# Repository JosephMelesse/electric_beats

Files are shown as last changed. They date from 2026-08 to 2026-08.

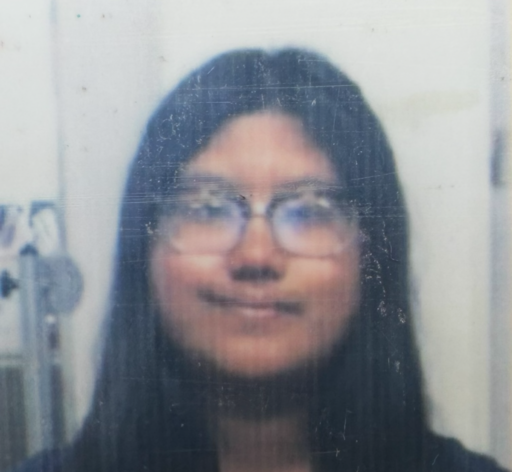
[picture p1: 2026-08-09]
web/client/src/assets/team_pics/ana_web.png

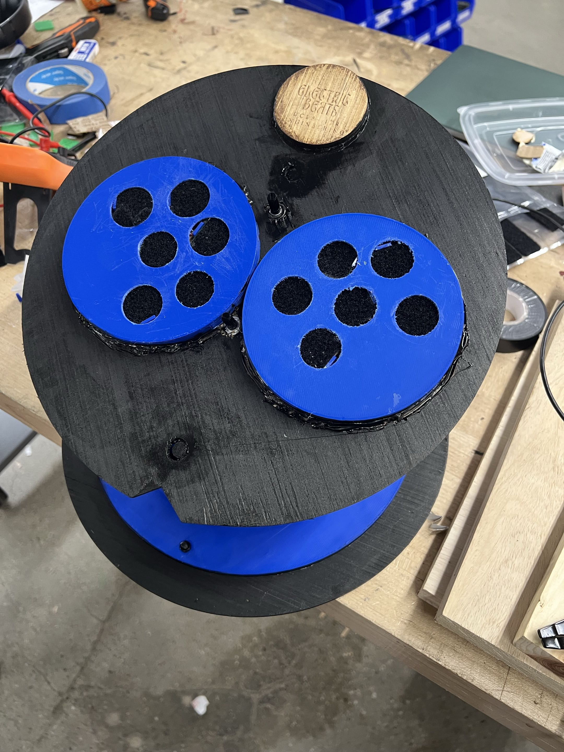
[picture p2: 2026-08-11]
web/client/src/assets/image.jpg

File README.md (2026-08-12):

# electric_beats

UCLA Engineering TR-1 Hack Project. A Pico 2 keypad wired to a browser. This
repo consists of the firmware, the web client and local server code, and any
miscellaneous files that are involved with the project.

It is a rhythm space shooter. A song stored in JSON schedules asteroids onto
twelve slots under a spaceship; press the matching key in time and the ship
turns and shoots. The Pico synthesizes the note it plays, so all audio comes
from the speaker on the board and the browser stays silent.

## Quick start

Copy the firmware to the board, then run the server:

```
cp firmware/code.py /media/$USER/CIRCUITPY/
cd web
npm install
npm start
```

Open http://localhost:5173 and press a key. Three songs ship in
`web/client/src/assets/song.json`; pick one from the menu above the canvas.

The board needs CircuitPython 10.x flashed once first, see `firmware/README.md`.

No board handy? The server still starts and serves the page, the game just
gets no input. There is no keyboard fallback.

Running the demo across two machines, one with the Pico and one on the
projector, is written up in `web/instruction.md`.

## Layout

| Path | What it is |
| --- | --- |
| `firmware/` | CircuitPython `code.py`, plus wiring and synth notes |
| `web/server/` | Serial bridge, websocket relay, static host |
| `web/client/` | React game canvas, bundled with esbuild |
| `misc/` | Sound sheets, pinout image, playing reference |

`DESIGN.md` covers the module split and what was cut.

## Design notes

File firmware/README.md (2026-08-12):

# Firmware

Reads twelve individual buttons, sends `K <key>` lines over USB serial at
115200, and synthesizes all game audio on the Pico. The browser is silent.

## Wiring

Each button connects its GPIO to GND; the firmware uses internal pull-ups.

| Signal | Pico 2 | Physical pin |
| --- | --- | --- |
| Buttons 1-6 | GP2, GP3, GP4, GP5, GP6, GP7 | 4, 5, 6, 7, 9, 10 |
| Button * | GP8 | 11 |
| Button 0 | GP9 | 12 |
| Button 9 | GP10 | 14 |
| Button 8 | GP11 | 15 |
| Button 7 | GP12 | 16 |
| Button # | GP13 | 17 |
| Amp I2S DIN | GP15 | 20 |
| Amp I2S BCLK | GP19 | 25 |
| Amp I2S LRC | GP20 | 26 |
| Amp VIN | VBUS 5V | 40 |
| Volume pot wiper | GP26 / ADC0 | 31 |
| Effect pot wiper | GP27 / ADC1 | 32 |
| Pot outer legs | 3V3 out and GND | 36, 38 |

The speaker (4 ohm, 3 W) connects directly to the amp's output terminals.
Do not put a resistor in the amp's power feed; if hardware attenuation is
ever needed again, it goes in series with a speaker wire.

## Sound

Each key plays one semitone of a chromatic scale from C4: `1` = C4 up to
`#` = B4, with `0` = A4 and `*` = A#4.

The volume pot (ADC0) sets the master level with a squared taper; full
clockwise is the MAX_VOLUME constant in `code.py`. Its outer legs are
wired so the ADC reads high at the quiet end, so `read_volume()` inverts
the reading; swap the pot's outer legs and that inversion comes out. The effect pot (ADC1)
selects the preset in three zones, left to right. A preset change only
affects new key presses. Zone edges have a dead band so a knob resting
on a boundary does not flicker.

Both knobs report over serial for the web client: `P <name>` for the
preset and `V <percent>` for the volume knob's position, each on change
and again every two seconds so a server that starts later catches up.
The percent is where the knob sits, not the level it produces, since
the taper is squared.

Each preset is a different waveform with a different effect on top, and
none is tied to a particular song:

| | bell (left) | reed (middle) | organ (right) |
| --- | --- | --- | --- |
| Waveform | chime | soft saw | drawbar organ |
| Effect | detune shimmer | 5.5 Hz vibrato | 4 Hz tremolo |
| Filter | low-pass 5 kHz | low-pass 3 kHz | low-pass 4 kHz |
| Release | 0.18 s | 0.15 s | 0.12 s |

Releases stay under 0.2 s so fast passages stay articulate. The tightest
spacing in the charts is a sixteenth at 70 bpm, about 214 ms, and a
longer tail would smear one note into the next.

All waveforms are built additively from sine harmonics that stay below
Nyquist, so naive saw/square aliasing cannot occur; filters are gentle
(Q 0.707) and note amplitudes are budgeted so summed voices cannot clip
inside the synth.

## Deploy

CircuitPython 10.x for the Pico 2 (flash the .uf2 from circuitpython.org
once), then copy `code.py` to the CIRCUITPY drive. It auto-reloads on
every copy; no build step. Everything used is built into CircuitPython,
no libraries to install.

Note: with CircuitPython the serial port carries the Python console, so
the server may see REPL noise besides the `K`, `P` and `V` lines; its
parser ignores anything that does not match one of those three.

The board and the server share `/dev/ttyACM0`, so stop the server before
opening a serial monitor such as `screen /dev/ttyACM0 115200`.

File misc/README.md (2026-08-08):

# misc

Reference material. Nothing here is built or imported by the code.

| File | What it is |
| --- | --- |
| `soundsheets.md` | Key map, frequencies, scales, chords, and playable melodies |
| `pinout.png` | Photo of the Pico 2 pinout used for wiring |

The authoritative wiring table is in `firmware/README.md`. The image is a
convenience, not the source of truth.

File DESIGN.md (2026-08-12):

# electric_beats

A rhythm space shooter played on a 4x3 matrix keypad. A song stored in JSON
schedules asteroids onto twelve slots arranged under a spaceship; pressing
the matching key in time makes the ship face the asteroid and shoot it.
All audio comes from the Pico's speaker, not the browser. The firmware
README documents the wiring, the synth patch, and the pot-selected effects.

## Modules

- `firmware/` keypad scan, `K <key>` serial output, and all sound.
- `web/server/` serves the client, bridges serial to the `/ws` websocket.
- `web/client/src/game/engine.js` pure game state: slots, song clock,
  spawn and expiry, hit detection, score.
- `web/client/src/pages/Game.jsx` canvas rendering and websocket input.
- `web/client/src/assets/song.json` tempo and the key sequence.

## Non-goals

Out of scope: multiple songs, keyboard input, score persistence.

Backlog: lives and a game over screen, hit timing grades, explosion
animation, bandlimited oscillators, audio effects (echo, bitcrush, wah).

## Riskiest parts

The engine's beat clock and hit windows, and the firmware's preset
switching at zone boundaries. No tests for this hack; verify by playing.

## Commands

- Server, from `web/`: `npm i`, then `npm run start`. Runs on
  http://localhost:5173.
- Client, from `web/client/`: `npm i`, then `npm run build` or
  `npm run watch`.
- No required environment variables. The serial device is hardcoded to
  `/dev/ttyACM0` in `web/server/index.js`; without the keypad the game
  runs but receives no input.

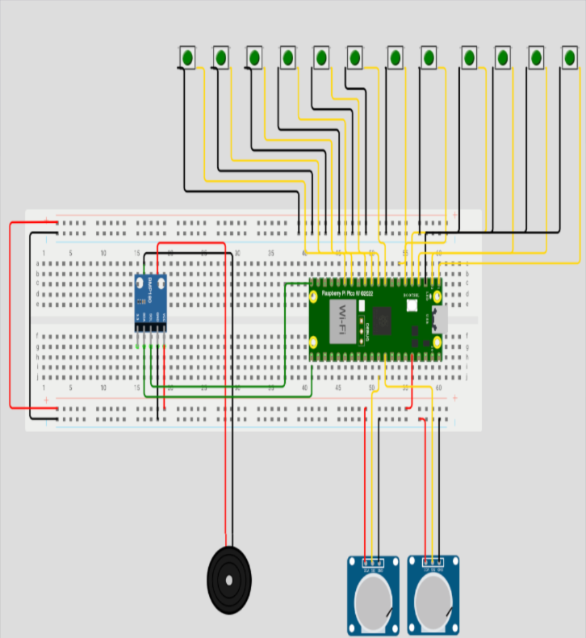
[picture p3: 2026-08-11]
circuit_schematics/v2.png

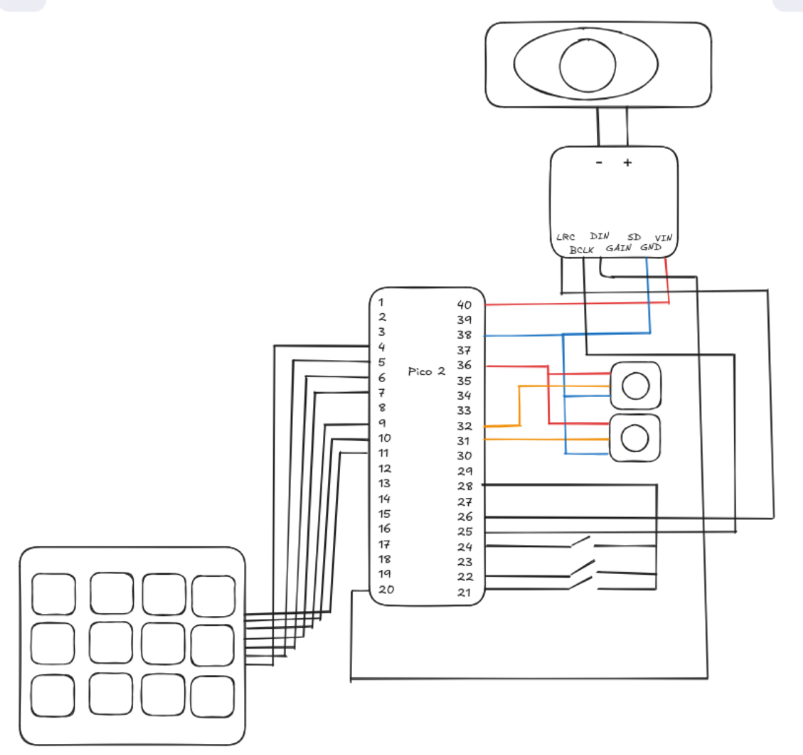
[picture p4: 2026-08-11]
circuit_schematics/v1.png

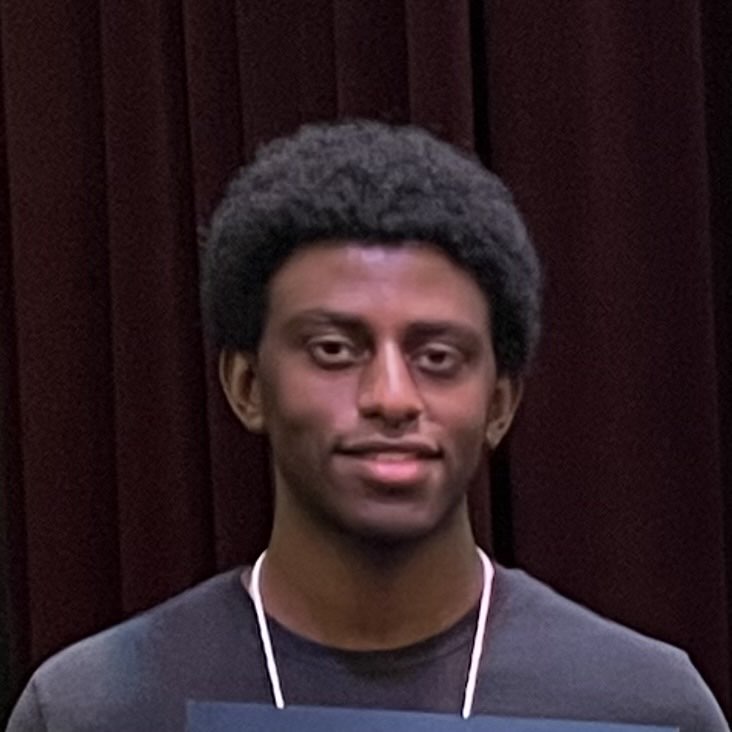
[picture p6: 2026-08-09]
web/client/src/assets/team_pics/joseph.jpg

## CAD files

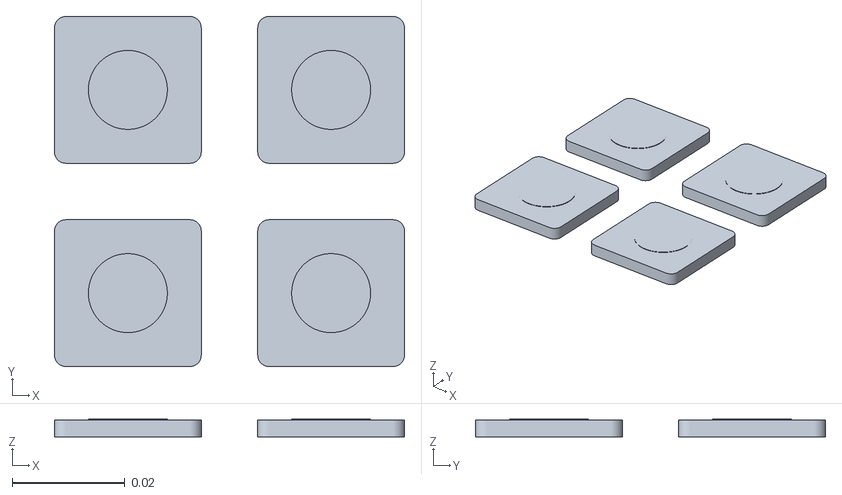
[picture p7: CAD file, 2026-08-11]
cad_files/keytiles (1).stl
0.062 x 0.062 x 0.0031

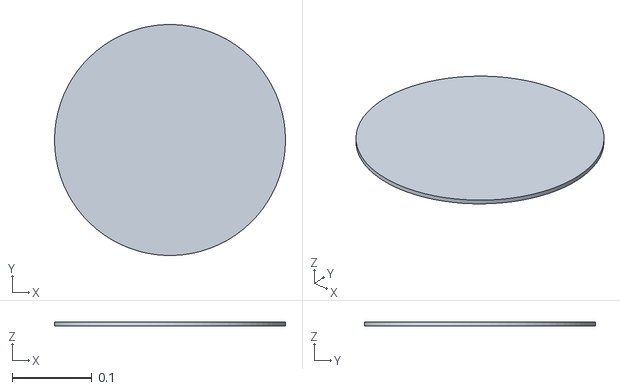
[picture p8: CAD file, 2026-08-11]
cad_files/Lid.stl
0.29 x 0.29 x 0.005

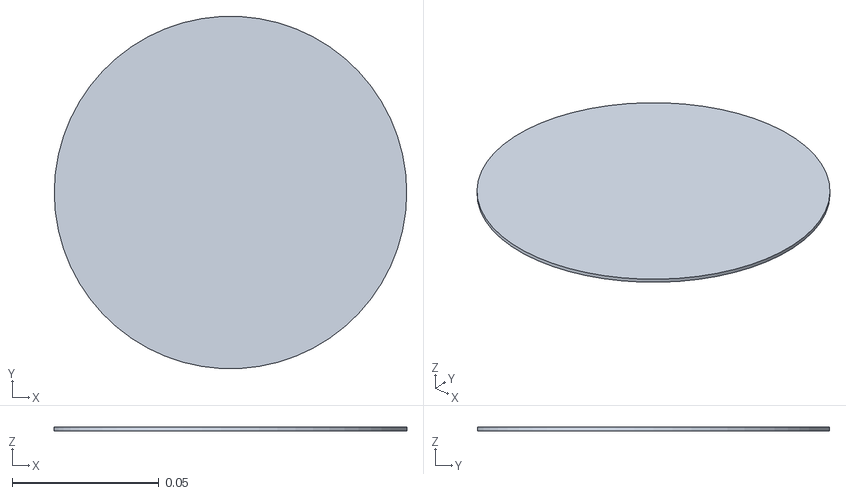
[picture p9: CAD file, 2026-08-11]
cad_files/lidforkeys.stl
0.12 x 0.12 x 0.0012

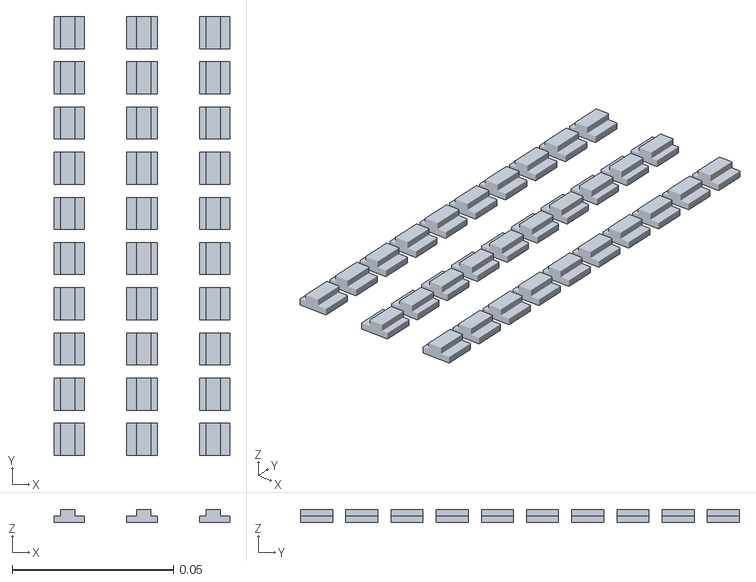
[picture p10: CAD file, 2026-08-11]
cad_files/Supports4keys (1).stl
0.0545 x 0.136 x 0.004

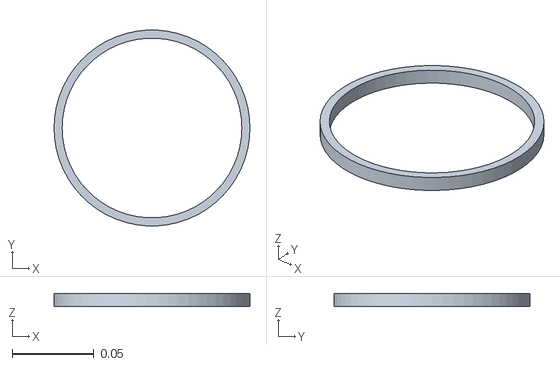
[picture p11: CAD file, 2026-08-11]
cad_files/keyWall.stl
0.12 x 0.12 x 0.008

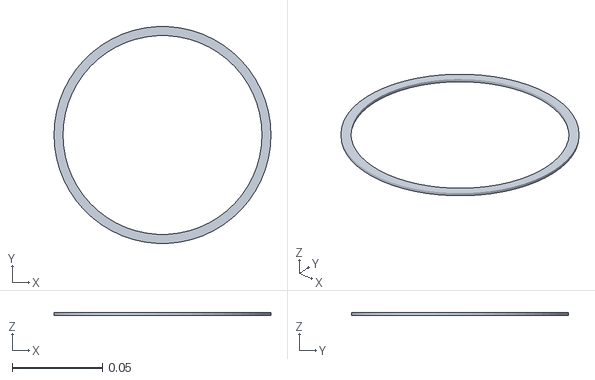
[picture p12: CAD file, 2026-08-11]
cad_files/booster.stl
0.12 x 0.12 x 0.0015

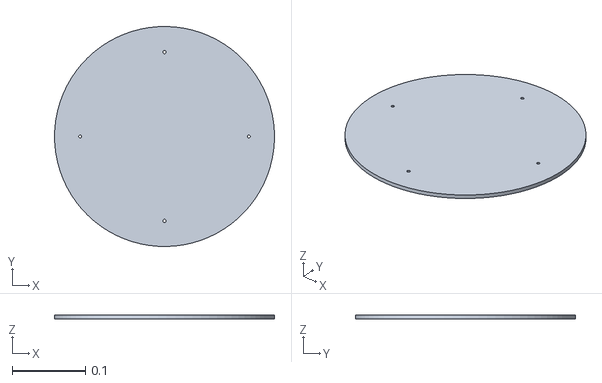
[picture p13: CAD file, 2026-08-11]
cad_files/Bottom.stl
0.3 x 0.3 x 0.005

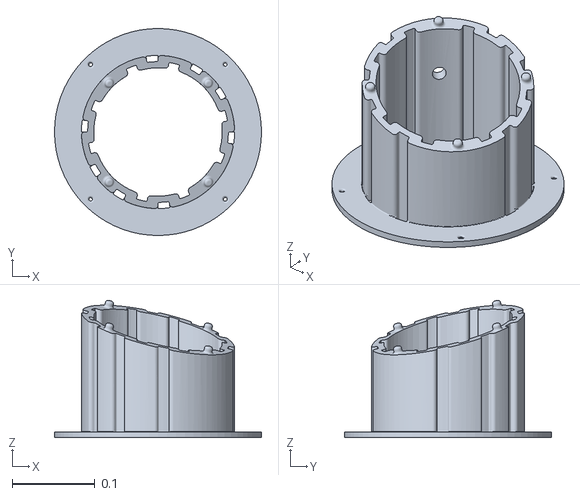
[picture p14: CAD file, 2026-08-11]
cad_files/Walls (1).stl
0.25 x 0.25 x 0.166

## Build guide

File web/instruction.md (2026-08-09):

# Running the demo on two computers

The Pico must be plugged into the machine running the server, because the
server reads the keypad over USB serial. The projector is driven by a
second machine that loads the same page in a browser. Both screens show
the game and stay in step.

- Server machine: runs the server, has the Pico on USB, shows the game.
- Projector machine: browser only, on the same network.

## Server machine

```
cd web
npm i
npm run start
```

That builds the client and starts the server on port 5173. Leave it
running. It prints two lines when healthy:

```
electric_beats on http://localhost:5173
keypad connected on /dev/ttyACM0
```

If it prints `keypad unavailable`, the Pico is not on `/dev/ttyACM0`.
Check that it is plugged in and that nothing else holds the port; a
serial monitor such as `screen` will block the server.

Open the game locally at:

```
http://localhost:5173
```

Find the machine's address for the projector machine to use:

```
ip -4 addr show scope global | grep -oP 'inet \K[\d.]+'
```

Pick the address on your actual network. On this machine that is
currently `172.28.88.71`, so the projector machine would open
`http://172.28.88.71:5173`. The address changes between networks, so
check it again at the venue.

## Projector machine

Open a browser and go to `http://<server-address>:5173`. Nothing to
install. Press F11 for fullscreen.

If the page does not load, work through these in order:

1. Both machines are on the same network, not one on guest wifi.
2. `ping <server-address>` from the projector machine.
3. The server machine's firewall allows port 5173. On Ubuntu, either
   `sudo ufw allow 5173` or turn the firewall off for the demo.
4. You used `http://`, not `https://`.

## How the two screens stay in step

Every screen runs its own copy of the game and draws natively, so both
look sharp. Keeping them together works like this:

- Key presses come from the Pico, through the server, out to every
  connected browser at once.
- Start, Retry and song selection do not act locally. The browser sends
  the request to the server, the server relays it to every browser, and
  each one acts when the message arrives. That includes the browser that
  sent it, so no screen jumps ahead.

The runs are therefore driven by the same events from the same instant
and stay together for the length of a song. They are separate engines,
not a video feed, so the two screens can drift by a frame. Scores match.

If the server is unreachable the buttons still drive the local screen
alone, so a single machine works with no server for layout work.

## Notes

- Start the demo from one screen only. Pressing Start on both is
  harmless, but pressing it twice sends two messages.
- Refreshing the projector machine mid-run gives it a fresh engine, so
  it will be out of step until the next Start or song change.
- Both browsers should be at the same zoom level, otherwise the canvas
  is scaled differently on each screen.

## Fallback

If the network at the venue blocks this, mirror the screen instead. On
the server machine run `x11vnc -display :0` and connect from the
projector machine with any VNC viewer, fullscreen. That is pixel
identical and needs no game changes, but it is a video stream, so it
looks softer and adds a little latency.

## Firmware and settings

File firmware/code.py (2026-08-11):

# electric_beats firmware, CircuitPython 10.x on a Pico 2.
# Reads twelve buttons, prints "K <key>" over USB serial, and plays each
# key's note through the I2S amp using synthio. The volume pot on ADC0
# sets the master level; the effect pot on ADC1 picks one of three
# presets in three zones. Each preset is a different waveform and works
# with any song; the name is printed as "P <name>" for the web client.

import math
import time

import analogio
import audiobusio
import audiomixer
import board
import keypad
import synthio
import ulab.numpy as np

SAMPLE_RATE = 22050

# Buttons wire each GPIO to GND; internal pull-ups, pressed reads low.
KEY_CHARS = "123456789*0#"
KEY_PINS = (
    board.GP2, board.GP3, board.GP4, board.GP5, board.GP6, board.GP7,
    board.GP12, board.GP11, board.GP10, board.GP8, board.GP9, board.GP13,
)

# Chromatic from C4: 1=C4 ... 0=A4, *=A#4, #=B4 (KEY_CHARS order).
NOTE_FREQ = (
    261.63, 277.18, 293.66, 311.13, 329.63, 349.23,
    369.99, 392.00, 415.30, 466.16, 440.00, 493.88,
)

# Waveforms are built additively from sine harmonics so they contain
# nothing above Nyquist: no aliasing fizz from naive saw/square edges.
WAVE_LEN = 256
WAVE_AMP = 12000


def additive(harmonics):
    x = np.linspace(0, 2 * math.pi, num=WAVE_LEN, endpoint=False)
    wave = np.zeros(WAVE_LEN)
    for k, amp in harmonics:
        wave = wave + amp * np.sin(k * x)
    peak = max(np.max(wave), -np.min(wave))
    return np.array(wave * (WAVE_AMP / peak), dtype=np.int16)


CHIME = additive(((1, 1.0), (2, 0.35), (3, 0.10), (4, 0.12)))
SOFT_SAW = additive(tuple((k, 1.0 / k) for k in range(1, 9)))
ORGAN = additive(((1, 0.9), (2, 0.6), (3, 0.4), (4, 0.25)))

VIBRATO = synthio.LFO(rate=5.5, scale=0.012)  # pitch wobble, ~15 cents
TREMOLO = synthio.LFO(rate=4.0, scale=0.25, offset=0.75)  # level 0.5-1.0

# One preset per effect-pot zone, left to right, each a different
# waveform with a different effect on top. "detune" adds a second
# oscillator slightly sharp for a shimmer; "bend"/"tremolo" attach an
# LFO to pitch or amplitude. Filters are gentle low-passes (Q 0.707),
# there to darken, not resonate.
#
# None of these is tied to a particular song. Releases are kept under
# 0.2 s so that fast passages stay articulate: the tightest spacing in
# the charts is a sixteenth at 70 bpm, about 214 ms, and a longer tail
# would smear one note into the next.
PRESETS = (
    {
        "name": "bell", "wave": CHIME, "detune": 1.006,
        "filter": 5000,
        "env": synthio.Envelope(
            attack_time=0.003, decay_time=0.20,
            sustain_level=0.35, release_time=0.18,
        ),
    },
    {
        "name": "reed", "wave": SOFT_SAW, "bend": VIBRATO,
        "filter": 3000,
        "env": synthio.Envelope(
            attack_time=0.015, decay_time=0.10,
            sustain_level=0.6, release_time=0.15,
        ),
    },
    {
        "name": "organ", "wave": ORGAN, "tremolo": TREMOLO,
        "filter": 4000,
        "env": synthio.Envelope(
            attack_time=0.008, decay_time=0.04,
            sustain_level=0.8, release_time=0.12,
        ),
    },
)

synth = synthio.Synthesizer(sample_rate=SAMPLE_RATE, channel_count=1)
i2s = audiobusio.I2SOut(
    bit_clock=board.GP19, word_select=board.GP20, data=board.GP15
)
mixer = audiomixer.Mixer(
    voice_count=1, sample_rate=SAMPLE_RATE, channel_count=1,
    bits_per_sample=16, samples_signed=True,
)
i2s.play(mixer)
mixer.voice[0].play(synth)

# Volume pot: squared taper so the useful range is not crammed into the
# first few degrees. Full clockwise is MAX_VOLUME, full range by default.
MAX_VOLUME = 1.0
POT_POLL = 0.02  # seconds between pot reads

pot_volume = analogio.AnalogIn(board.GP26)
pot_preset = analogio.AnalogIn(board.GP27)

# Preset pot zone edges, with a dead band so a knob resting on an edge
# does not flicker between presets.
ZONE_EDGES = (65536 // 3, 2 * 65536 // 3)
ZONE_DEAD = 3000


def preset_zone(raw, current):
    if raw < ZONE_EDGES[0] - ZONE_DEAD:
        return 0
    if ZONE_EDGES[0] + ZONE_DEAD < raw < ZONE_EDGES[1] - ZONE_DEAD:
        return 1
    if raw > ZONE_EDGES[1] + ZONE_DEAD:
        return 2
    return current


def pot_to_level(avg):
    return (avg / 65535) ** 2 * MAX_VOLUME


def read_volume():
    # This pot's outer legs are wired so the ADC reads high at the quiet
    # end. Inverting here means everything downstream, the mixer level
    # and the reported percent alike, sees plain knob position.
    return 65535 - pot_volume.value


vol_avg = read_volume()
level = pot_to_level(vol_avg)
mixer.voice[0].level = level
preset_index = preset_zone(pot_preset.value, 0)
next_poll = time.monotonic()

# Knob position as a whole percent, reported as "V <percent>" for the
# web client's volume bar. This is where the knob sits, not the level
# it produces: the taper below is squared, so a bar drawn from the
# level would sit at a quarter with the knob at half way.
volume_pct = int(vol_avg * 100 / 65535)

# Preset and volume are re-announced on this interval as well as on
# change. The server usually starts after the board is already running,
# so it would otherwise miss the boot announcement and show nothing
# until a knob was moved.
ANNOUNCE_EVERY = 2.0
next_announce = time.monotonic()

keys = keypad.Keys(KEY_PINS, value_when_pressed=False, pull=True)

active = {}  # key number -> tuple of notes


def make_notes(k):
    p = PRESETS[preset_index]
    filt = synthio.Biquad(synthio.FilterMode.LOW_PASS, p["filter"], Q=0.707)
    note = synthio.Note(
        frequency=NOTE_FREQ[k], waveform=p["wave"],
        envelope=p["env"], filter=filt,
    )
    if "bend" in p:
        note.bend = p["bend"]
    if "tremolo" in p:
        note.amplitude = p["tremolo"]
    detune = p.get("detune")
    if not detune:
        return (note,)
    note.amplitude = 0.5
    return (note, synthio.Note(
        frequency=NOTE_FREQ[k] * detune, waveform=p["wave"],
        envelope=p["env"], filter=filt, amplitude=0.5,
    ))


while True:
    now = time.monotonic()
    if now >= next_poll:
        next_poll = now + POT_POLL
        # Light smoothing keeps ADC noise from making the level jitter.
        vol_avg += (read_volume() - vol_avg) * 0.2
        new_level = pot_to_level(vol_avg)
        if abs(new_level - level) > MAX_VOLUME / 200:
            level = new_level
            mixer.voice[0].level = level
            # Reported here rather than every poll so ADC noise cannot
            # flicker the bar back and forth while the knob sits still.
            pct = int(vol_avg * 100 / 65535)
            if pct != volume_pct:
                volume_pct = pct
                print("V", volume_pct)
        zone = preset_zone(pot_preset.value, preset_index)
        if zone != preset_index:
            preset_index = zone
            next_announce = now
    if now >= next_announce:
        next_announce = now + ANNOUNCE_EVERY
        print("P", PRESETS[preset_index]["name"])
        print("V", volume_pct)

    event = keys.events.get()
    if event:
        if event.pressed:
            print("K", KEY_CHARS[event.key_number])
            old = active.pop(event.key_number, None)
            if old:
                synth.release(old)
            notes = make_notes(event.key_number)
            active[event.key_number] = notes
            synth.press(notes)
        else:
            notes = active.pop(event.key_number, None)
            if notes:
                synth.release(notes)

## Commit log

2026-08-08 setup the boilerplate using a node server, react client, and arduino firmware
2026-08-09 rewrote firmware in circuit python to take advantage of synthio
2026-08-11 removed samples to work purely on synthio
2026-08-11 added cad files
    [Bottom.stl, Lid.stl, Supports4keys (1).stl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]
2026-08-11 added circuit schematics
